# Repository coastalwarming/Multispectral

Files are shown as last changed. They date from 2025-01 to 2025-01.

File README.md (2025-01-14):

# Multispectral
<table class="table table-hover table-striped table-bordered">
  <tr align="center">
   <td>Multispectral 1 Image</td>
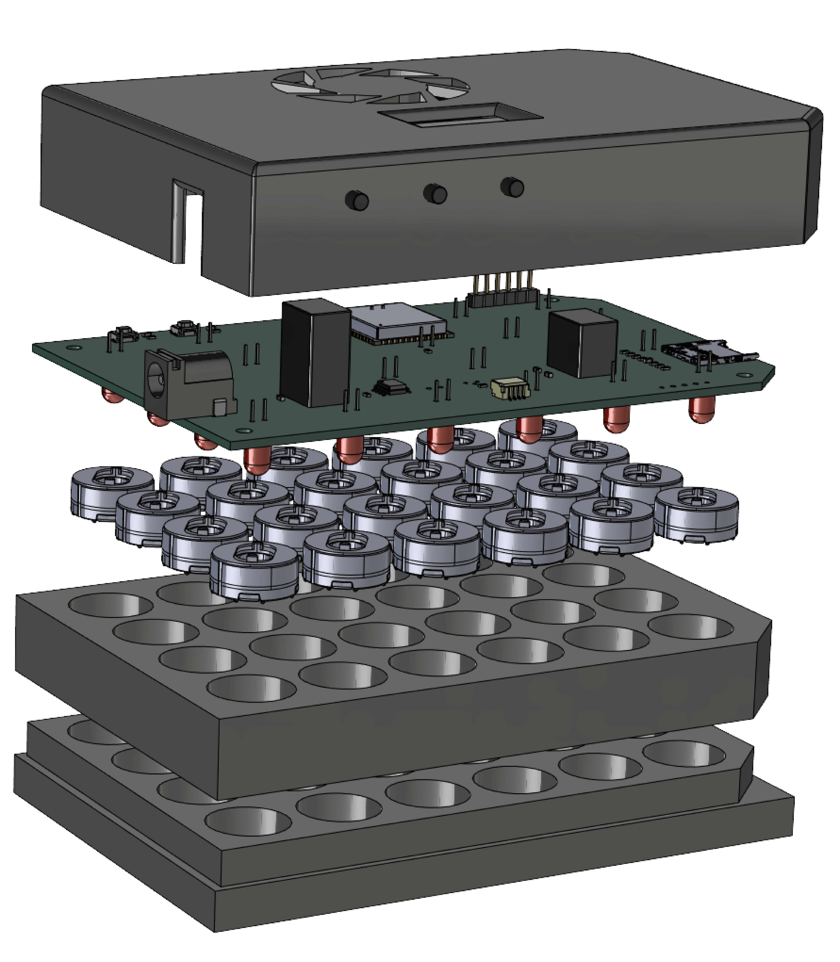
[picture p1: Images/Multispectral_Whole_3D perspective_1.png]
Multispectral 2 Image
   <td></td>
  </tr>
</table>
The Multipectal is a prototype to conduct photobiology experiments in a 24 well microplates that can apply individual light intensities at each well on na continuous and dynamic profile. Designed with affordability and scalability in mind, this innovative approach facilitates a wide range of experimental applications in photobiology and optogenetics.

Repository Contents
-------------------

* **/Documents** - Profile maker and example
* **/Hardware** - kicad PCB files
* **/Firmware** - Cpp firmware (Arduino IDE)
* **/Mechanical** - Structural parts
* **/BOM** - Complete list of components and cost
* **/Images** - Images from the device

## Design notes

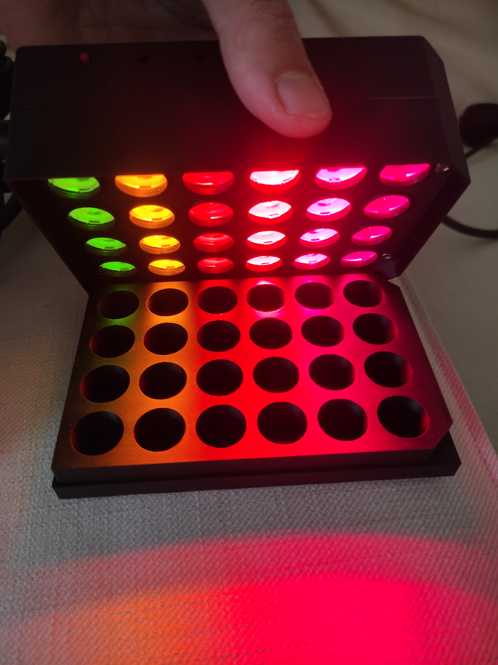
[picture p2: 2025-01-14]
Images/570nm to 680nm specter.jpg

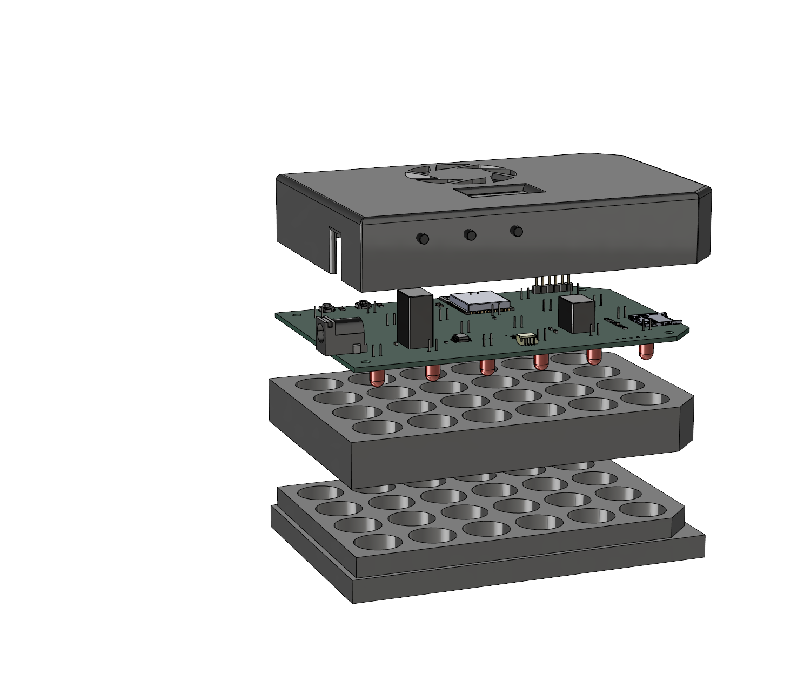
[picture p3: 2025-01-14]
Mechanical/Multispectral_Whole_3D perspective.PNG

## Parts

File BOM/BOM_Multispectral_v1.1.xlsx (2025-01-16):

Nº | Item | Item | Ref | Supplier | Units
 |  | 3D filament | Matte Charcoal (11101) | Bambulab | 1
1 | Capacitor 0.1uF 0603 | PCB | Eurocircuits | Mouser | 1
2 | Resistor 10k 0603 | Capacitor 0.1uF 0603 | VJ0603Y104KCXAT | Mouser | 7
3 | Capacitor 22uF Electrolytic 0603 | Capacitor 1uF 0603 | 06036C105MAT2A (https://www.mouser.se/ProductDetail/KYOCERA-AVX/06036C105MAT2A) | Mouser | 2
5 | Capacitor 47uF Electrolytic | Capacitor 22uF 0603 | GRM188C61E226ME01J | Mouser | 1
6 | Resistor 1k 0603 | Capacitor 10uF 0603 | GRM188C61E106ME01J | Mouser | 2
7 | Resistor 470R 0603 | Resistor 10 K Ohm 0603 | RT0201BRE0710KL | Mouser | 11
8 | Led RED SMD | Resistor 46.4 Ohm 0603 | TNPW060346R4BEEN | Mouser | 24
9 | ESP32U | Resistor 100 K Ohm 0603 | RT0201BRE07100KL | Mouser | 3
10 | Transformer AC/DC 230AC->3.3DC | Resistor 4.7 K Ohm 0603 | RT0201BRE074K7L | Mouser | 2
11 | RV3032 RTC | LED driver | TLC5947DAP | Mouser | 1
12 | Solid state relay | Microcontroller | ESP32-S3-WROOM-1 | Mouser | 1 | C0603C104K4RACTU (https://pt.mouser.com/ProductDetail/KEMET/C0603C104K4RACTU?qs=l5k%252BbMnNDknCtKnMv1oEgA%3D%3D) | Mouser | 8
13 | Socket Fuse 20x5mm PCB | Switch PCB | EVQP2 | Mouser | 2 | RCS060310K0JNEA (https://pt.mouser.com/ProductDetail/Vishay-Dale/RCS060310K0JNEA?qs=NKmfXavxMaxOSWu%252BIfGj8A%3D%3D) | Mouser | 6
14 | Fuse 5A Fast 20x5mm | Switch panel | SW_SPST_TL3305B | Mouser | 2 | CL10A226MPCNUBE (https://pt.mouser.com/ProductDetail/Samsung-Electro-Mechanics/CL10A226MPCNUBE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) | Mouser | 1
15 | Fuse 630mA Fast 20x5mm | Transistors PNP | MMBT3906 | Mouser | 24 | CRGH0603F4K7 (https://pt.mouser.com/ProductDetail/TE-Connectivity-Holsworthy/CRGH0603F4K7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) | Mouser | 3
16 | Switch EVQP2 | 3.3 V DCDC regulator | R-78E3.3-1.0 | Mouser | 1 | 865230243003 (https://pt.mouser.com/ProductDetail/Wurth-Elektronik/865230243003?qs=0KOYDY2FL290Qfc6XUy%2FFw%3D%3D) | Mouser | 1
17 | Keystone_3000_1x12mm-CoinCell | 5 V DCDC regulator | R-78K5.0-2.0 | Mouser | 1 | CRT0603-FY-1001ELF (https://pt.mouser.com/ProductDetail/Bourns/CRT0603-FY-1001ELF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) | Mouser | 2
18 | Battery coincell CR1220 | 12V External Transformer | SWM30-12-EV-P5 | Mouser | 1 | RC0603FR-7W470RL (https://pt.mouser.com/ProductDetail/YAGEO/RC0603FR-7W470RL) | Mouser | 3
19 | Transistor BC817 | Fan 40x40mm 12V Fan | CFM-4010V-150-157 | Mouser | 1 | APTD1608LSURCK (https://pt.mouser.com/ProductDetail/Kingbright/APTD1608LSURCK) | Mouser | 2
20 | MicroSD socket | Transistor NPN BC817 | BC817 | Mouser | 1 | ESP32-WROOM-32UE-N8 (https://pt.mouser.com/ProductDetail/Espressif-Systems/ESP32-WROOM-32UE-N8?qs=Li%252BoUPsLEntX6CSaKZB9vw%3D%3D) | Mouser | 1
21 | Card uSD 32Gb | Mosfet 12V for FAN | IRF7425PBF | Mouser | 1 | 190-7732 (https://pt.rs-online.com/web/p/fuentes-de-alimentacion-de-modo-conmutado-smps-integradas/1907732) | RS | 1
22 | Connector 3x1 para 230AC Male Vertical | microSD socket | 503398-1892 | Mouser | 1 | RV-3032-C7 32.768kHz-2.5PPM-TA-QC (https://pt.mouser.com/ProductDetail/Micro-Crystal/RV-3032-C7-32.768kHz-2.5PPM-TA-QC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) | Mouser | 1
23 | Connector 3x1 para 230AC Female Vertical | Barrel jack for power supply | 485-373 | RS | 1 | 849-CPC40055ST (https://pt.mouser.com/ProductDetail/849-CPC40055ST) | Mouser | 2
24 | Connector 3x1 for Sensor Temperatur3 Female Vertical | microSD card 32GB | SC1628 | Mouser | 1 | 563-756 (https://pt.rs-online.com/web/p/montajes-para-pcb/0563756/?searchHistory=%7B%22enabled%22%3Atrue%7D) | RS | 3
25 | Connector 3x1 for Sensor Temperatur3 Male Vertical |  |  |  |  | 0217005.MXBP (https://pt.mouser.com/ProductDetail/Littelfuse/0217005MXBP) | Mouser | 2
26 | 6x1 2.54mm FTDI pins | LEDs models successfully tested: |  |  |  | Fuse 0034.1514 (https://pt.mouser.com/ProductDetail/Schurter/00341514?qs=sGAEpiMZZMsIz3CjQ1xegWrlMY7vL59hXKFC6EezV8k%3D) | Mouser | 1
27 | Antenna | LED_395nm | OSUG5111A-OP | Mouser |  | EVQ-P2V02M (https://pt.mouser.com/ProductDetail/Panasonic/EVQ-P2V02M?qs=RY%2FkUk5H9K3t0RdrQiYChQ%3D%3D) | Mouser | 2
28 | Connector Antenna SMA RP-female to U.FL | LED_425nm | HLMP-EL10-13K00 | Mouser |  | 534-3000 (https://pt.mouser.com/ProductDetail/Keystone-Electronics/3000?qs=Mn60vILZNNbcLh3ZnzbtUw%3D%3D) | Mouser | 1
29 | Sensor temperature | LED_440nm | MTE6800N2-UR | Mouser |  | 866-0653 (https://nl.rs-online.com/web/p/button-batteries/8660653) | RS | 1
30 | Cable gland for Sensors M12 | LED_465nm | HLMP-EG08-WZ000 | Mouser |  | BC817K-16R (https://pt.mouser.com/ProductDetail/Nexperia/BC817K-16R) | Mouser | 2
31 | Cable gland Power supply 230v and heaters M16 | LED_500nm | 150141SS63140 | Mouser |  | 503398-1892 (https://pt.mouser.com/ProductDetail/Molex/503398-1892?qs=sGAEpiMZZMsBCPBs0T0YsMHADqEpeRrEOv75VDk3f8w%3D) | Mouser | 1
32 | Waterproof box | LED_525nm | SSL-LX5093SRC/F | Mouser |  | SDSDQAB-032G-1 (https://www.mouser.com/ProductDetail/SanDisk/SDSDQAB-032G-1?qs=EgF7oUuTQmqFn5RjeZ0Jwg%3D%3D) | Mouser | 1
33 | PCB | LED_570nm | OSUG5111A-OP | Mouser |  | 897-1247 (https://pt.rs-online.com/web/p/conectores-macho-para-pcb/8971247) | RS | 3
 |  | LED_591nm | HLMP-EL10-13K00 | Mouser |  | 897-1212 (https://pt.rs-online.com/web/p/bloques-terminales-para-pcb/8971212) | RS | 3
 |  | LED_626nm | HLMP-EG08-WZ000 | Mouser |  | TJ0331530000G (https://pt.mouser.com/ProductDetail/Amphenol-Anytek/TJ0331530000G?qs=Mv7BduZupUgxbQyc5spAlA%3D%3D) | Mouser | 2
 |  | LED_640nm | 150141SS63140 | Mouser |  | OQ0332500000G (https://pt.mouser.com/ProductDetail/Amphenol-Anytek/OQ0332500000G?qs=Mv7BduZupUjnTZnwMLgCeA%3D%3D) | Mouser | 2
 |  | LED_660nm | SSL-LX5093SRC/F | Mouser |  | 251-8632 (https://pt.rs-online.com/web/p/conectores-macho-para-pcb/2518632/?searchHistory=%7B%22enabled%22%3Atrue%7D) | RS | 1
 |  | LED_680nm | MTE6800N2-UR | Mouser |  | TANGO25A/0.1M/SMAM/S/RP/29 (https://pt.rs-online.com/web/p/antenas-wifi/1248720/?searchHistory=%7B%22enabled%22%3Atrue%7D) | RS | 1
 |  | LED_720nm | MT5720-IR | Mouser |  | 852 (https://pt.mouser.com/ProductDetail/Adafruit/852?qs=sGAEpiMZZMsKEdP9slC0YZXhkLAMiYPKq57Kua0w3%2Fc%3D) | Mouser | 1
 |  | LED_740nm | MTE1074N1-R | Mouser |  | SEN-11050 (https://pt.mouser.com/ProductDetail/SparkFun/SEN-11050) | Mouser | 2
 |  | LED_765nm | MTE2077N1-R | Mouser |  | Cable gland M12 | MaisAutomacao | 2
 |  | LED_810nm | MTE2081-OH5 | Mouser |  | Cable gland M16 | MaisAutomacao | 3
 |  |  |  |  |  | Eldon_Policarbonato anti-Uv DPCP121609GE | MaisAutomacao (16 unidades) | 1
 |  |  |  |  |  | Eurocircuits _ 48 batch | Eurocircuits | 1

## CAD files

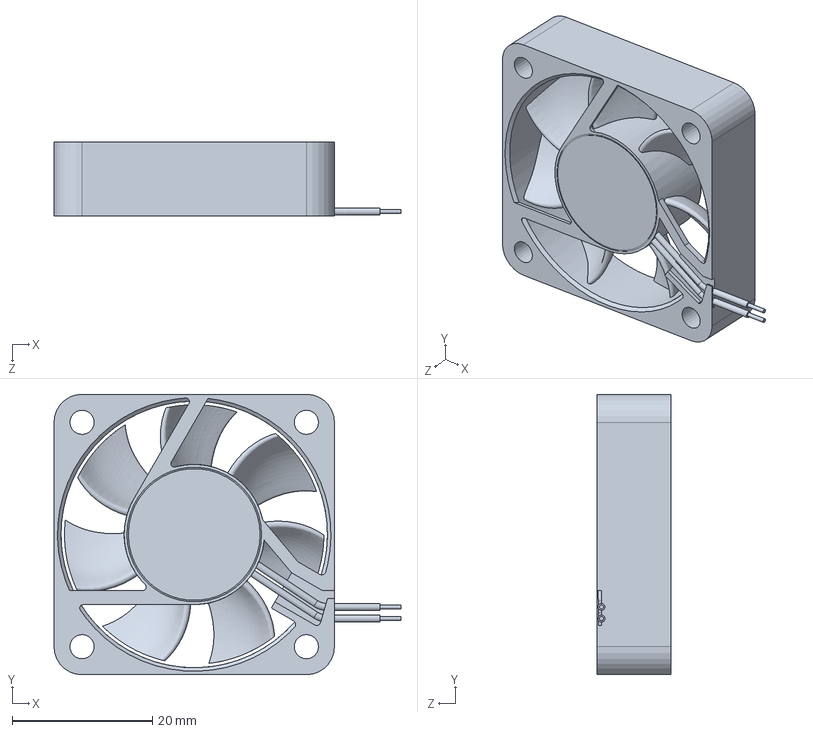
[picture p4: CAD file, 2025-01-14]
Mechanical/40x40x10 DC Fan.SLDPRT
49.5 x 40.0 x 10.5 mm

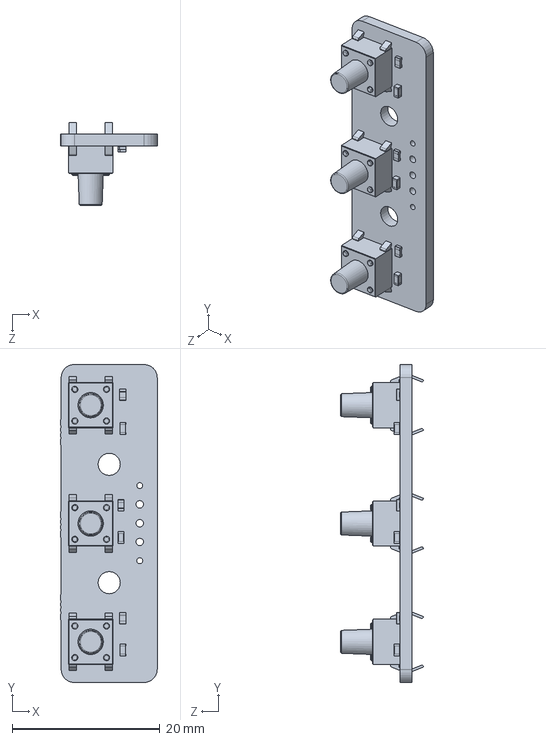
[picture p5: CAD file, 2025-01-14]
Mechanical/Buttons PCB.SLDPRT
13.1 x 43.0 x 11.2 mm

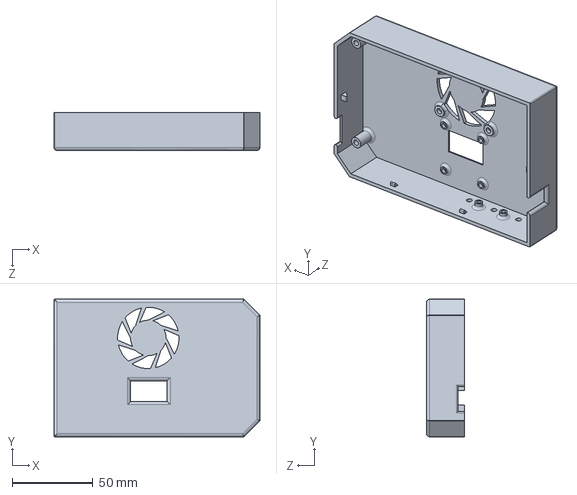
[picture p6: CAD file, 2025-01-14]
Mechanical/Lid.SLDPRT
127.5 x 85.2 x 23.5 mm

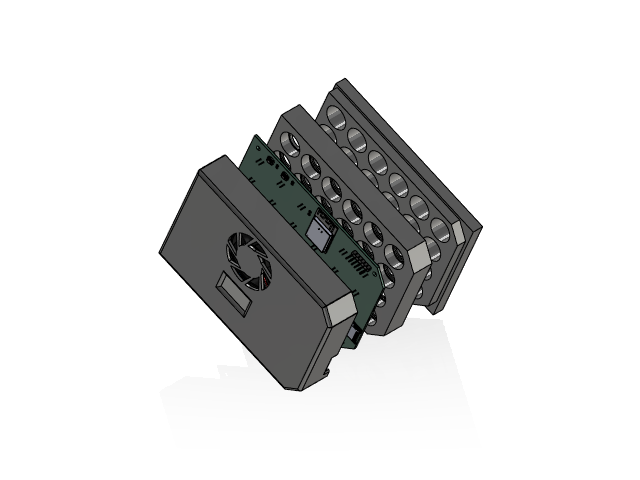
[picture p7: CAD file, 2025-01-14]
Mechanical/Whole device 3D assembly .SLDASM
3_Tampa para a placa do Serodio desenhada por mim no SW
Placa do Serodio desenhada por mim no SW
Matrix_LED_PCB_Main
Adafruit 0.96in 128x64 OLED STEMMA QT
Matrix_LED_PCB_SoBotoes_altos
tampa_ecra_Short_profile_corrigida_v2_10mm_short_Fan_simple_grill
40x40x10 DC Fan

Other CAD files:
Mechanical/Lid.STL

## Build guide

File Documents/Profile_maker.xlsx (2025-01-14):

Seconds until next step | Coluna 1 |  |  |  | Coluna 2 |  |  |  | Coluna 3 |  |  |  | Coluna 4 |  |  |  | Coluna 5 |  |  |  | Coluna 6 |  |  |  | Limit temperature | Profile.txt
 | LED_1 | LED_2 | LED_3 | LED_4 | LED_5 | LED_6 | LED_7 | LED_8 | LED_9 | LED_10 | LED_11 | LED_12 | LED_13 | LED_14 | LED_15 | LED_16 | LED_17 | LED_18 | LED_19 | LED_20 | LED_21 | LED_22 | LED_23 | LED_24
 |  |  |  |  |  |  |  |  |  |  |  |  |  |  |  |  |  |  |  |  |  |  |  |  | 30.1 | 30.1
3600 | 100 | 100 | 100 | 100 | 100 | 100 | 100 | 100 | 100 | 100 | 100 | 100 | 100 | 100 | 100 | 100 | 100 | 100 | 100 | 100 | 100 | 100 | 100 | 100 |  | 3600-100100100100100100100100100100100100100100100100100100100100100100100100
360 | 75 | 75 | 75 | 75 | 75 | 75 | 75 | 75 | 75 | 75 | 75 | 75 | 75 | 75 | 75 | 75 | 75 | 75 | 75 | 75 | 75 | 75 | 75 | 75 |  | 360-075075075075075075075075075075075075075075075075075075075075075075075075
360 | 50 | 50 | 50 | 50 | 50 | 50 | 50 | 50 | 50 | 50 | 50 | 50 | 50 | 50 | 50 | 50 | 50 | 50 | 50 | 50 | 50 | 50 | 50 | 50 |  | 360-050050050050050050050050050050050050050050050050050050050050050050050050
360 | 25 | 25 | 25 | 25 | 25 | 25 | 25 | 25 | 25 | 25 | 25 | 25 | 25 | 25 | 25 | 25 | 25 | 25 | 25 | 25 | 25 | 25 | 25 | 25 |  | 360-025025025025025025025025025025025025025025025025025025025025025025025025
360 | 0 | 0 | 0 | 0 | 0 | 0 | 0 | 0 | 0 | 0 | 0 | 0 | 0 | 0 | 0 | 0 | 0 | 0 | 0 | 0 | 0 | 0 | 0 | 0 |  | 360-000000000000000000000000000000000000000000000000000000000000000000000000

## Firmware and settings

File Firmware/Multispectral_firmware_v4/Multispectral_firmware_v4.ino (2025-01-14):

const int  Version = 4;
const int Low_temp_limit = 0, High_temp_limit = 50;


#include <Update.h>



#define FAN_GPIO 6
const int freq = 3000;
//A nova ventoinha n funciona a <3000Khz.
//COm 1kHz faz ruido em 50% mas nao faz a >60% intensidade. Solução foi 3500Hz e 4.7KOhm de pullup no gate.
const int ledChannel = 0;
const int resolution_PWM = 8;

//DS18B20
#include <OneWire.h>
#include <DallasTemperature.h>
#define ONE_WIRE_BUS 5
OneWire oneWire(ONE_WIRE_BUS);
DallasTemperature sensors(&oneWire);
DeviceAddress tempDeviceAddress;
unsigned long lastTempRequest = 0;
float temperature = 0.0, Prev_temp = -1;
int resolution_DS18B20 = 11;
//

//TLC5947
#include "Adafruit_TLC5947.h"
#define NUM_TLC5947 1
#define Data 11 //-> MOSI (GPIO11 no ESP32S3) || MOSI (GPIO23 no ESP32E) -> TLC5947 Pino 4 (SIN)
#define Clock 12 //-> SCK (GPIO12 no ESP32S3) || SCK (GPIO18 no ESP32E)  -> TLC5947 Pino 3 (SCLK)
#define latch 4 //-> Qualquer pino (Ex: GPIO4 no ESP32S3)                -> TLC5947 Pino 30 (XLAT)
#define oe -1  // set to -1 to not use the enable pin (its optional)
bool SD_Failed = false, SD_detected = false, SD_was_undecteted = false, SD_returned = false;
Adafruit_TLC5947 tlc = Adafruit_TLC5947(NUM_TLC5947, Clock, Data, latch);
//

//SW
#define Btn1_GPIO   17
#define Btn2_GPIO   15
#define Btn3_GPIO   16
const int Debounce_ms = 500;

volatile bool Switch_1 = false;
volatile bool Switch_2 = false;
volatile bool Switch_3 = false;

volatile unsigned long Millis_Botao_passed = 0, Millis_Botao_passed_3 = 0;

bool Switch1_foi_pressionado_3s = false;
//

//OLED
#include <SPI.h>
#include <Wire.h>

#include <Adafruit_GFX.h>
#define SCREEN_WIDTH 128 // OLED display width, in pixels
#define SCREEN_HEIGHT 64 // OLED display height, in pixels
#define SSD1306_NO_SPLASH
#include <Adafruit_SSD1306.h>

#define OLED_RESET     -1 // Reset pin # (or -1 if sharing Arduino reset pin)
#define SCREEN_ADDRESS 0x3D ///< See datasheet for Address via i"C scanner code.
Adafruit_SSD1306 display(SCREEN_WIDTH, SCREEN_HEIGHT, &Wire, -1);

byte Stage = 0;
int   Passo = 0;//changed from 0 to 1
volatile bool Switch3_foi_pressionado_3s = false;

//

bool Running_running = false;

unsigned int profileTimes[26][100];
unsigned int LEDs_Light[26][24][100];

float profileSetpoint[26];

char profileLetters[26];
byte profileLength[100];

int profileTimes_sec[100];
int profileTimes_min[100];
int profileTimes_h[100];

bool Running_experiment = false;
unsigned long Start_time = 0;


#include "FS.h"
#include "SD_MMC.h"

/**/
#define Detect_SD_PIN 1 //Tem de ter 10k pullup.
#define DEBOUNCETIME 20
File file;
volatile int numberOfButtonInterrupts_SD = 0;
volatile bool lastState_SD;
volatile uint32_t debounceTimeout_SD = 0;
int SD_detect_state = -1;

portMUX_TYPE mux = portMUX_INITIALIZER_UNLOCKED;
void IRAM_ATTR handleButtonInterrupt_SD() {
  portENTER_CRITICAL_ISR(&mux);
  numberOfButtonInterrupts_SD++;
  lastState_SD = !digitalRead(Detect_SD_PIN);
  debounceTimeout_SD = xTaskGetTickCount(); //version of millis() that works from interrupt
  portEXIT_CRITICAL_ISR(&mux);
}
TaskHandle_t Task_gerir_SD;
/**/


//Timer de contar segundos:
volatile int segundos;
volatile bool Second_F = false;

hw_timer_t * timer = NULL;
portMUX_TYPE timerMux = portMUX_INITIALIZER_UNLOCKED;

bool Screen_0_Drawn = false,
     Screen_1_Drawn = false,
     Screen_2_Drawn = false,
     Screen_3_Drawn = false,
     Screen_4_Drawn = false;

void IRAM_ATTR onTimer() {

  segundos++;

  portENTER_CRITICAL_ISR(&timerMux);
  Second_F = true;//Esta variavel é colocada a zero no decorrer da experiencia para saber que ja ajustou o segundo que passou.
  portEXIT_CRITICAL_ISR(&timerMux);
}
//

volatile byte Index_letter_screen = 0;
volatile byte Nr_Letters = 0;
bool Sw1_Sw2_detached = false;
void setup() {

  Serial.begin(115200);

  Serial.printf("Firmware version:v%i .\n", Version);
  //PWM
  pinMode(FAN_GPIO, OUTPUT);
  //ledcSetup(ledChannel, freq, resolution_PWM);
  //ledcAttachPin(FAN_GPIO, ledChannel);

  //

  //DS18B20
  sensors.begin();
  sensors.getAddress(tempDeviceAddress, 0);
  sensors.setResolution(tempDeviceAddress, resolution_DS18B20);
  sensors.setWaitForConversion(false);
  sensors.requestTemperatures();
  //delayInMillis = 750 / (1 << (12 - resolution));
  lastTempRequest = millis();
  //

  //TLC5947
  tlc.begin();
  if (oe >= 0) {
    pinMode(oe, OUTPUT);
    digitalWrite(oe, LOW);
  }

  //tlc.begin();
  Desligar_LEDS();
  //

  //SW
  pinMode(Btn1_GPIO, INPUT);
  pinMode(Btn2_GPIO, INPUT);
  pinMode(Btn3_GPIO, INPUT);

  attachInterrupt(Btn1_GPIO, &Ext_INT1_ISR, FALLING);//RISING, FALLING,CHANGE, LOW .
  attachInterrupt(Btn2_GPIO, &Ext_INT2_ISR, FALLING);//RISING, FALLING,CHANGE, LOW .
  attachInterrupt(Btn3_GPIO, &Ext_INT3_ISR, FALLING);//RISING, FALLING,CHANGE, LOW .
  //

  //OLED
  if (!display.begin(SSD1306_SWITCHCAPVCC, SCREEN_ADDRESS)) { //Obtive pelo scan de addrress de i2c.
    Serial.println(F("SSD1306 allocation failed"));
    for (;;); // Don't proceed, loop forever
  }
  //

  //Timer segundos:
  timer = timerBegin(0, 80, true);
  timerAttachInterrupt(timer, &onTimer, true);
  timerAlarmWrite(timer, 1000000, true);//1000000
  //timerAlarmEnable(timer);
  //timerAlarmDisable(timer);
  //timerWrite(timer, 0);//-> Faz reset ao timer.

  //

  /**/
  pinMode(Detect_SD_PIN, INPUT_PULLUP);  // Pull up to 3.3V on input - some buttons already have this done
  attachInterrupt(digitalPinToInterrupt(Detect_SD_PIN), handleButtonInterrupt_SD, CHANGE);//FALLING
  handleButtonInterrupt_SD();//Corre logo a interrupcao para detetar se botao ja esta pressionado.
  //Task
  xTaskCreatePinnedToCore(
    taskButtonRead_SD,   // função que implementa a tarefa
    "taskButtonRead_SD", // nome da tarefa
    2000,      // número de palavras a serem alocadas para uso com a pilha da tarefa
    NULL,       // parâmetro de entrada para a tarefa (pode ser NULL)
    1,          // prioridade da tarefa (0 a N)
    &Task_gerir_SD,       // referência para a tarefa (pode ser NULL)
    0);         // Núcleo que executará a tarefa

  delay(2000);
  /**/

  if (!SD_MMC.setPins(20, 21, 35, 36, 37, 38)) {//bool setPins(int clk, int cmd, int d0, int d1, int d2, int d3);// NO DEVKitM S3 o 33 e 34 nao tem breakout
    Serial.println("Failed pin setup");
    SD_Failed = true;
  }


  if (SD_detected) {
    if (!SD_MMC.begin()) {
      Serial.println("Card Mount Failed");
      SD_Failed = true;
      return;
    }
  } else {
    //Card absent.
    Serial.println("Card is not being detected.");

    display.setTextColor(WHITE);
    display.setTextSize(1);
    display.setCursor(5, 25);
    display.println("No SD card.");
    display.display();
    while (!SD_detected) {
      delay(1000);
    }

    //SD detected:
    //Apagar
    display.setTextColor(BLACK);
    display.setTextSize(1);
    display.setCursor(5, 25);
    display.println("No SD card.");
    display.display();
    //Escrever
    display.setTextColor(WHITE);
    display.setTextSize(1);
    display.setCursor(5, 25);
    display.println("SD card detected.");
    display.display();

    display.setCursor(5, 35);
    display.println("Rebooting...");
    display.display();
    delay(2000);
    display.fillScreen(BLACK);

    ESP.restart();

  }

  if (SD_Failed && SD_detected) {
    //Card corrupted.
    Serial.println("Card is being detected but does not mount - possibly corrupted.");

    display.setTextSize(1);
    display.setCursor(5, 25);
    display.println("SD card is corrupted.");
    display.display();
    while (SD_detected) {
      delay(1000);
    }
    while (!SD_detected) {
      delay(1000);
    }

    //SD detected:
    //Apagar
    display.setTextColor(BLACK);
    display.setTextSize(1);
    display.setCursor(5, 25);
    display.println("SD card is corrupted.");
    display.display();
    //Escrever
    display.setTextColor(WHITE);
    display.setTextSize(1);
    display.setCursor(5, 25);
    display.println("SD card detected.");
    display.display();

    display.setCursor(5, 35);
    display.println("Rebooting...");
    display.display();
    delay(2000);
    display.fillScreen(BLACK);
    ESP.restart();



  }

  updateFromFS(SD_MMC);


  Count_Profiles(SD_MMC, "/", 0);
  //GetProfile_SD(SD_MMC, "/B.txt");



}

void loop() {
  if (Stage == 0)Print_Screen_0();//Choosing
  if (Stage == 1)Print_Screen_1();//Countdown to start
  if (Stage == 2)Run_experiment();//Experiment
  if (Stage == 3)Print_Screen_3();//Cancel
  if (Stage == 4)Print_Screen_4();//Finish

  if (Running_experiment) Run_experiment();
  Check_SW3_Long_press();

  if (SD_returned) {

    display.fillScreen(BLACK);

    //Escrever
    display.setTextColor(WHITE);
    display.setTextSize(1);
    display.setCursor(5, 25);
    display.println("SD card detected.");
    display.display();

    display.setCursor(5, 35);
    display.println("Rebooting...");
    display.display();
    delay(2000);
    display.fillScreen(BLACK);
    ESP.restart();
  }


  /*
    portENTER_CRITICAL(&timerMux);
    if (Second_F) {
      Serial.println(segundos);
      Second_F = false;
    }
    portEXIT_CRITICAL(&timerMux);
  */
}

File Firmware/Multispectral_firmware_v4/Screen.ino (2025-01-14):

void Print_Screen_0() {
  static byte Prev_Stage = -1;
  static byte Prev_Index_letter_screen = 255;

  if (Sw1_Sw2_detached) {
    attachInterrupt(Btn1_GPIO, &Ext_INT1_ISR, FALLING);//RISING, FALLING,CHANGE, LOW .
    attachInterrupt(Btn2_GPIO, &Ext_INT2_ISR, FALLING);//RISING, FALLING,CHANGE, LOW .
    Sw1_Sw2_detached = false;
  }

  //
  if (!Screen_0_Drawn) {
    display.setTextColor(WHITE);
    display.clearDisplay();
    Prev_temp = -1;

    display.setTextSize(1);
    display.setCursor(0, 5);
    display.println("Choose Program:");
    display.display();

    display.setCursor(65, 25);
    display.println("Steps");
    display.display();

    display.setCursor(108, 57);
    display.setTextSize(1);
    char Temp[10];
    snprintf_P(Temp, sizeof(Temp), PSTR("v%i"), Version);
    display.println(Temp);
    display.display();

    Prev_Stage = -1;
    Prev_Index_letter_screen = 255;
    Screen_0_Drawn = true;
    Switch3_foi_pressionado_3s = false;
  }
  //

  //Atualizar Temperatura:
  Update_Temp();
  //

  //Re-Desenhar o texto movel:
  if (Prev_Index_letter_screen != Index_letter_screen) {
    //Apagar:
    if (Prev_Index_letter_screen != 255) {//So para filtrar o escrever a preto a primeira letra de todas que nao existe no 255.
      //Apagar letra grande:
      display.setTextColor(BLACK);
      display.setTextSize(2);
      display.setCursor(15, 25);
      display.println(profileLetters[Prev_Index_letter_screen]);
      display.display();
      //Apagar steps :
      display.setTextSize(1);
      display.setCursor(50, 25);
      display.println(profileLength[Prev_Index_letter_screen]);
      display.display();
      //Apagar tempo :
      display.setCursor(50, 35);
      char Temp[10];
      snprintf_P(Temp, sizeof(Temp), PSTR("%02i:%02i:%02i"),
                 profileTimes_h[Prev_Index_letter_screen],
                 profileTimes_min[Prev_Index_letter_screen],
                 profileTimes_sec[Prev_Index_letter_screen]);
      display.println(Temp);
      display.display();
      //Escrever temperatura ::
      display.setCursor(50, 45);
      char Temp_13[7];
      snprintf_P(Temp_13, sizeof(Temp_13), PSTR("%.1f C"),
                 profileSetpoint[Prev_Index_letter_screen]);
      display.println(Temp_13);
      display.display();
      //Apagar indice de passos :
      display.setCursor(100, 45);
      char Temp_2[10];
      snprintf_P(Temp_2, sizeof(Temp_2), PSTR("%i/%i"),
                 Prev_Index_letter_screen + 1,
                 Nr_Letters + 1);
      display.println(Temp_2);
      //Final de Apagar.

    }

    //Escrever novo:
    //Escrever letra grande::
    display.setTextColor(WHITE);
    display.setTextSize(2);
    display.setCursor(15, 25);
    display.println(profileLetters[Index_letter_screen]);
    display.display();
    //Escrever steps ::
    display.setTextSize(1);
    display.setCursor(50, 25);
    display.println(profileLength[Index_letter_screen]);
    display.display();
    //Escrever tempo ::
    display.setCursor(50, 35);
    char Temp_3[10];
    snprintf_P(Temp_3, sizeof(Temp_3), PSTR("%02i:%02i:%02i"),
               profileTimes_h[Index_letter_screen],
               profileTimes_min[Index_letter_screen],
               profileTimes_sec[Index_letter_screen]);
    display.println(Temp_3);
    display.display();
    //Escrever temperatura ::
    display.setCursor(50, 45);
    char Temp_12[7];
    snprintf_P(Temp_12, sizeof(Temp_12), PSTR("%.1f C"),
               profileSetpoint[Index_letter_screen]);
    display.println(Temp_12);
    display.display();
    //Escrever indice de passos :
    display.setCursor(100, 45);
    char Temp_4[10];
    snprintf_P(Temp_4, sizeof(Temp_4), PSTR("%i/%i"),
               Index_letter_screen + 1,
               Nr_Letters + 1);
    display.println(Temp_4);
    display.display();
    //Final de Escrever novo.

    Prev_Index_letter_screen = Index_letter_screen;

    if (Switch_1)Switch_1 = false;
    if (Switch_2)Switch_2 = false;
    if (Switch_3)Switch_3 = false;

  }
  //Final de Re-Desenhar o texto movel:

  //

}

void Print_Screen_1() {
  static byte time_ = 3;
  static unsigned long currentMillis, previousMillis = 0;

  if (!Screen_1_Drawn) {
    detachInterrupt(Btn1_GPIO);
    detachInterrupt(Btn2_GPIO);
    Sw1_Sw2_detached = true;

    //Apagar Texto do Screen 0:
    display.setTextColor(WHITE);
    display.clearDisplay();
    Prev_temp = -1;

    //Escrever Texto do Screen 1:
    display.setTextColor(WHITE);
    display.setTextSize(2);
    display.setCursor(15, 25);
    display.println(profileLetters[Index_letter_screen]);
    display.display();

    display.setTextSize(1);
    display.setCursor(50, 05);
    display.println("Starting in:");
    display.display();

    time_ = 3;
    currentMillis = 0;
    previousMillis = 0;
    Screen_1_Drawn = true;

  }

  //Atualizar Temperatura:
  //Update_Temp();
  //

  currentMillis = millis();
  if ((currentMillis - previousMillis >= 1000) && time_ != 255) {
    // save the last time you blinked the LED
    previousMillis = currentMillis;

    //Apagar numero:
    if (time_ != 3) {
      display.setTextColor(BLACK);
      display.setTextSize(2);
      display.setCursor(80, 25);
      display.println(time_ + 1);
      display.display();
    }


    //Escrever numero:
    display.setTextColor(WHITE);
    display.setTextSize(2);
    display.setCursor(80, 25);
    display.println(time_);
    display.display();

    time_--;

  }

  if (time_ == 255)Stage = 2;
}
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
